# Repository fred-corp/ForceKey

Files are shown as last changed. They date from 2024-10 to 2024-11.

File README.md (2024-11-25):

# Force Key

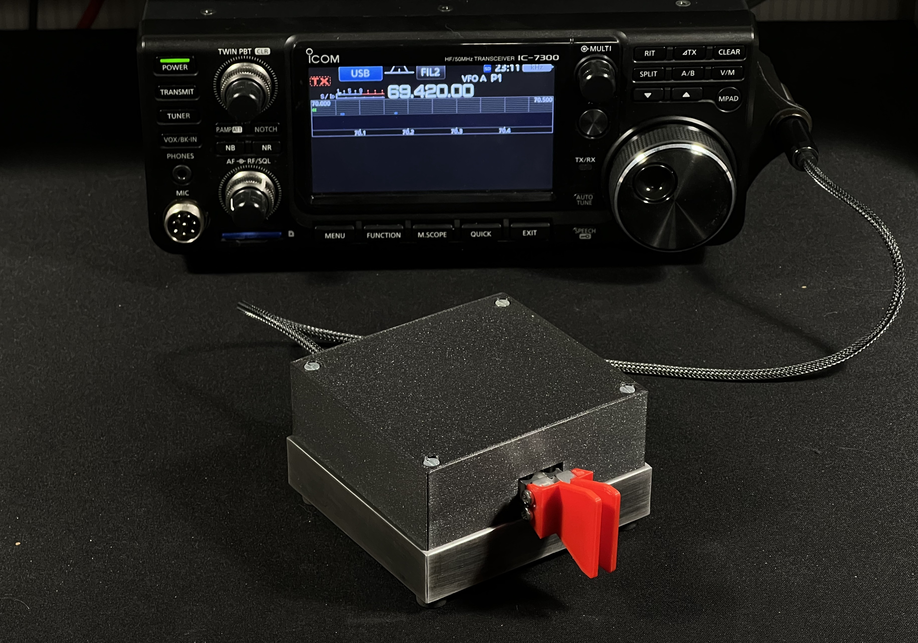
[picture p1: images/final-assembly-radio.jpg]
Force key image


## Description

The Force Key solid-state morse paddle key, which, as the name implies, uses force senors (load cells) to detect the user's input. It is designed to work in single-lever mode or twin-lever mode.  
The output is a standard 3.5mm stereo jack, which can be connected to any morse keyer or transceiver.

## Features

- Single-lever or twin-lever mode, or both at the same time
- Adjustable sensitivity in code
- TRS 3.5mm stereo jack output (tip = dot, ring = dash, sleeve = ground)
- Li-Ion battery powered
- USB-C port for charging
- Uses cheap Puya microcontroller

## Hardware

- PCB & other components in BOM
- 2x [100g load cells + HX711 amplifier](https://fr.aliexpress.com/item/1005001537354199.html) (make sure to get the 100g version !)
- TODO: add more details

The HX711 has to be modded to output data at 80Hz rate, which is done by lifting pin 15 and bridging it to pin 16 :  
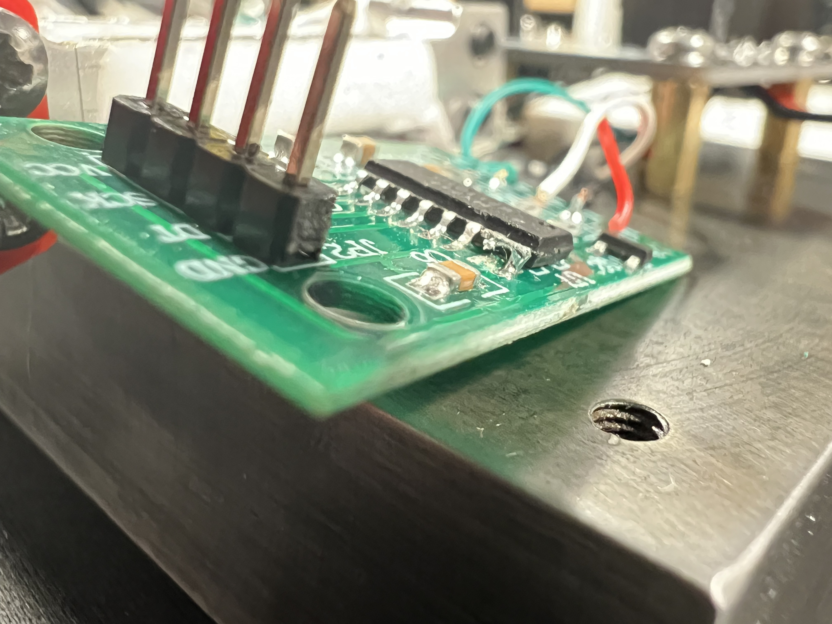
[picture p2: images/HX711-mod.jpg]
HX711 mod


## Inspiration

The Force key is inspired by the [Solid State Paddle by 9A5N](https://www.9a5n.eu/paddle.html), which is a beautiful product; but because of my student budget, I decided to make my own version.  
It was a nice challenge as I wanted to use the Puya PY32F002A microcontroller, which is not very common in the maker community.  
I also wanted to machine the base and load cell supports myself, which was exciting as I don't get to use the mills and lathes of my university very often as I'm an EE student.

Please consider buying the original product if you can afford it, it's a great product and it's worth the price (thanks [F4IEY](https://github.com/f4iey) for showing it to me in the first place !).

## Pictures

### 3D Render from Autodesk Fusion

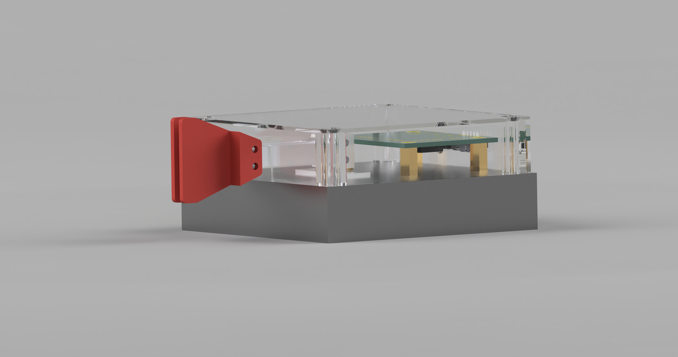
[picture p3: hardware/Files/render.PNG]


### Base machining

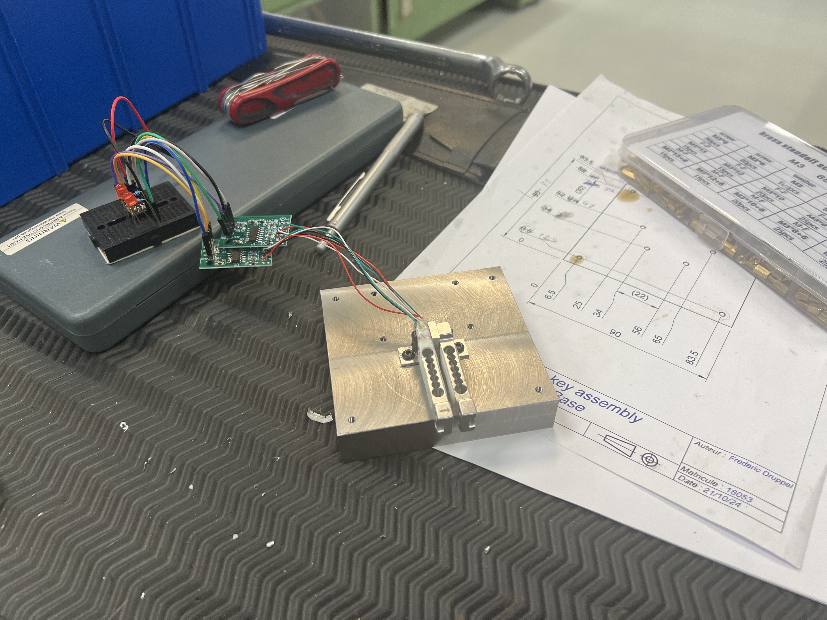
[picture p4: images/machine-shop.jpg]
machine shop


The final base ended up being 90x85x20mm due to the available scrap blank; the CAD was then adapted to fit the new dimensions.

It was amazing to be able to use the machines of my university. It took a whole afternoon to machine both parts (base and load-cell support), but it was really fun ! Thanks again to my teacher for all the help and advice.

### Base bluing

Before :  
before bluing

After :  
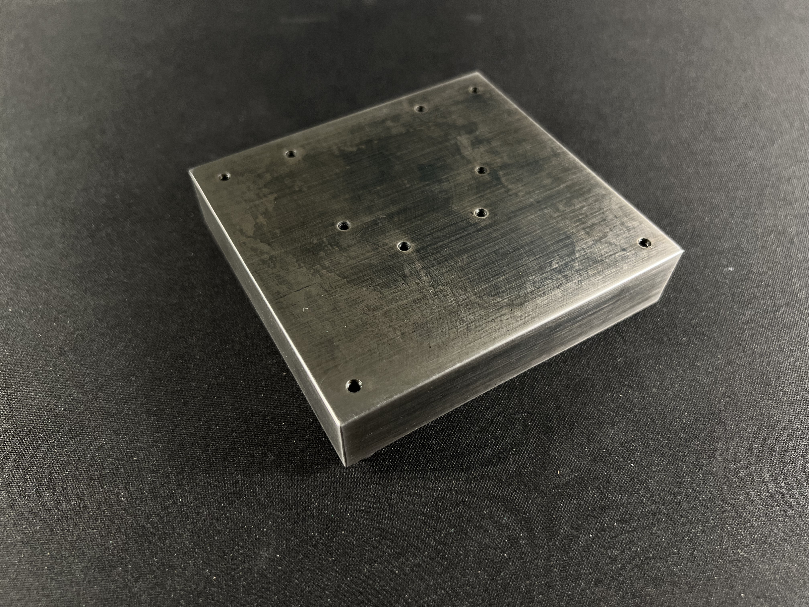
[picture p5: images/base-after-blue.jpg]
after bluing


After a lot of sanding with 180 and 320 scotch-brite, I used a cold bluing solution to give the base a nice black finish. It's not perfect nor uniform, but it gives a great old-school look to the base.

### Assembly

Partial assembly before bluing :  
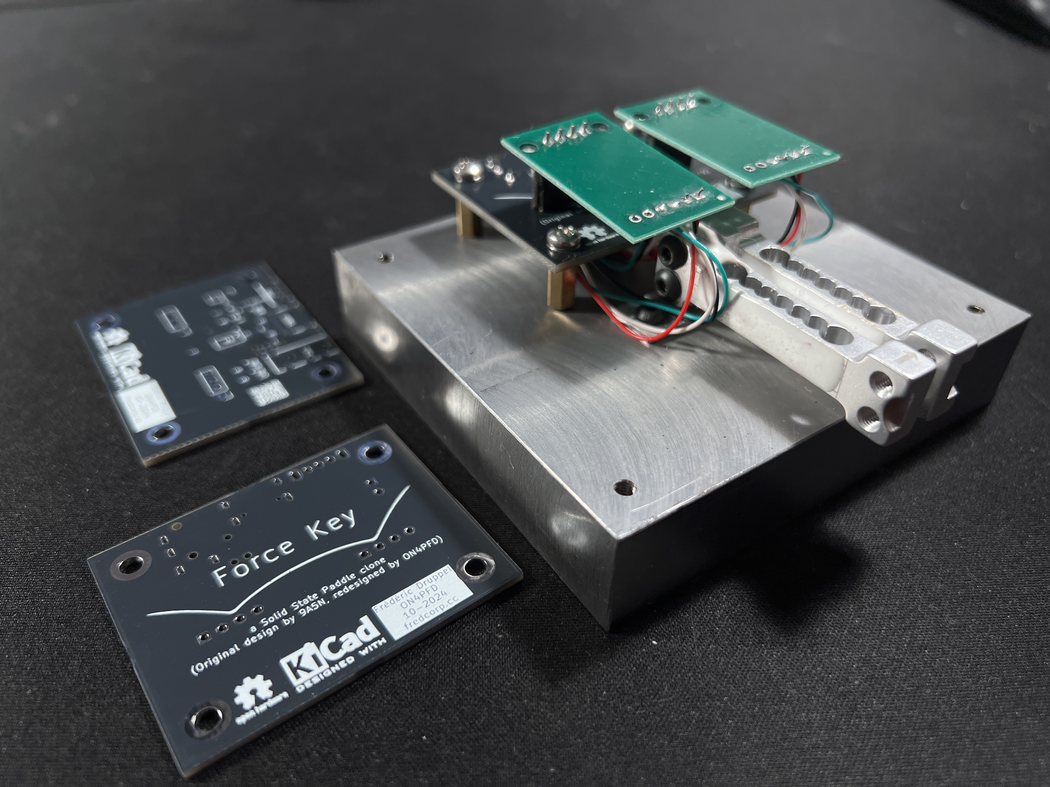
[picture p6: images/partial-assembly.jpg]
assembly


Assembly before bluing :  
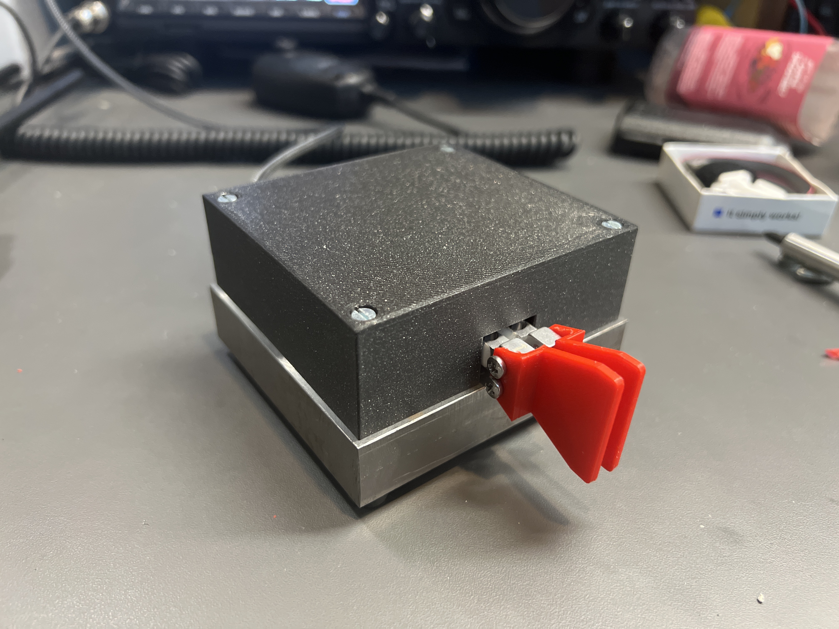
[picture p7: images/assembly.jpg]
assembly


Partial assembly after bluing :
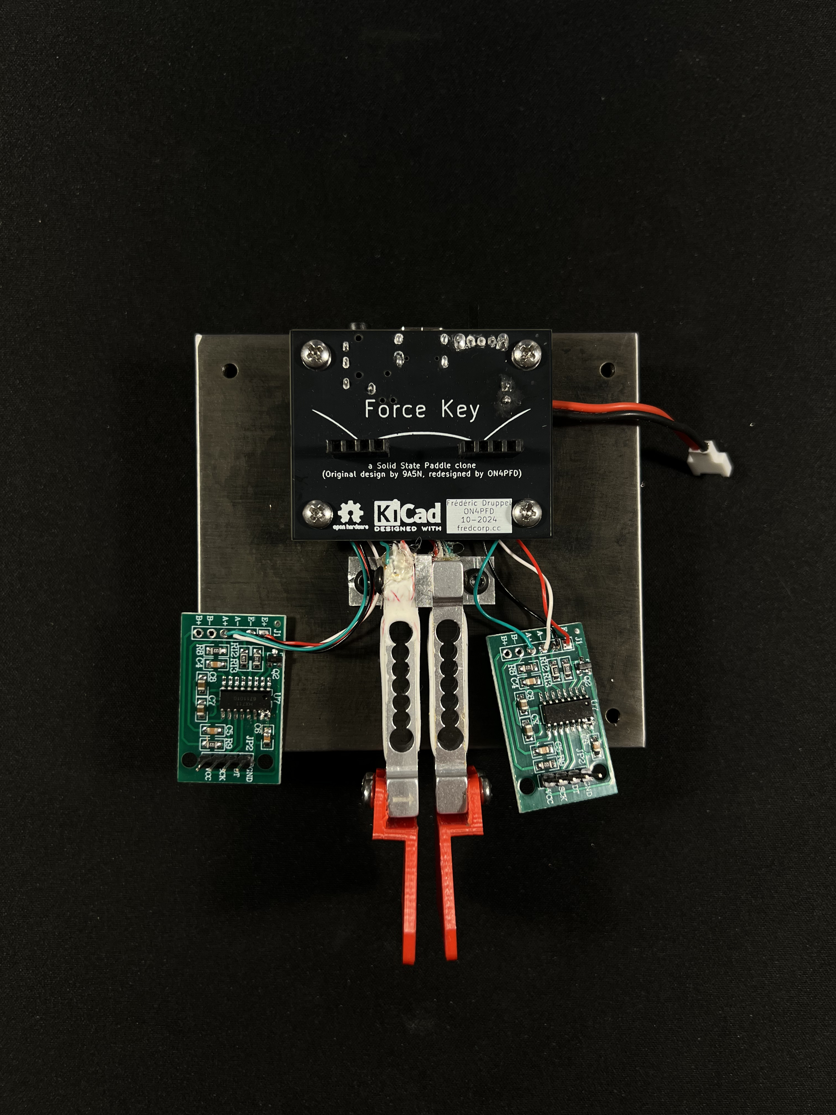
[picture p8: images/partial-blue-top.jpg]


Final assembly :

assembly

## License & Acknowledgements

Made with ❤️, lots of ☕️, and lack of 🛌  
Published under CreativeCommons BY-SA 4.0

  
This work is licensed under a [Creative Commons Attribution-ShareAlike 4.0 International License](http://creativecommons.org/licenses/by-sa/4.0/).

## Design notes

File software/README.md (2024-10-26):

# py32f0-template

* Template project for Puya PY32F0 MCU
* Supports GNU Arm Embedded Toolchain
* Supports J-Link and DAPLink/PyOCD programmers
* Supports IDE: VSCode

## Puya PY32F0 Family

PY32F0 are cost-effective Arm Cortex-M0+ microcontrollers featured with wide range operating voltage from 1.7V to 5.5V. Datesheets and Reference Manuals can be found at [WIKI](https://github.com/IOsetting/py32f0-template/wiki).

### PY32F002B

Frequency up to 24 MHz, 24 Kbytes of Flash memory, 3 Kbytes of SRAM.

* PY32F002B
  * PY32F002Bx(24KB Flash/3KB RAM)

### PY32F0xx

Frequency up to 48 MHz, 16 to 64 Kbytes of Flash memory, 3 to 8 Kbytes of SRAM.

* PY32F002A
  * PY32F002Ax5(20KB Flash/3KB RAM)
* PY32F003
  * PY32F003x4(16KB Flash/2KB RAM), PY32F003x6(32KB Flash/4KB RAM), PY32F003x8(64KB Flash/8KB RAM)
* PY32F030
  * PY32F030x4(16KB Flash/2KB RAM), PY32F030x6(32KB Flash/4KB RAM), PY32F030x8(64KB Flash/8KB RAM)

### PY32F07x

Frequency up to 72 MHz, 128 Kbytes of Flash memory, 16 Kbytes of SRAM, with more peripherals(CAN, USB)

* PY32F040
  * PY32F040xB(128KB Flash/16KB RAM)
* PY32F071
  * PY32F071xB(128KB Flash/16KB RAM)
* PY32F072
  * PY32F072xB(128KB Flash/16KB RAM)

## File Structure

```txt
├── Build                       # Build results
├── Docs                        # Datesheets and User Manuals
├── Examples
│   ├── PY32F002B               # PY32F002B examples
│   │   ├── HAL                 # HAL library examples
│   │   └── LL                  # LL(Low Layer) library examples
│   ├── PY32F07x                # PY32F07x examples
│   │   └── HAL                 # HAL library examples
│   └── PY32F0xx                # PY32F002A,PY32F003,PY32F030 examples
│       ├── FreeRTOS            # FreeRTOS examples
│       ├── HAL                 # HAL library examples
│       └── LL                  # LL(Low Layer) library examples
├── Libraries
│   ├── CMSIS
│   ├── EPaper                  # Waveshare e-paper library
│   ├── FreeRTOS                # FreeRTOS library
│   ├── LDScripts               # LD files
│   ├── PY32F002B_HAL_BSP       # PY32F002B HAL BSP
│   ├── PY32F002B_HAL_Driver    # PY32F002B HAL library
│   ├── PY32F002B_LL_BSP        # PY32F002B LL(low layer) BSP
│   ├── PY32F002B_LL_Driver     # PY32F002B LL library
│   ├── PY32F07x_HAL_BSP        # PY32F040/071/072 HAL BSP
│   ├── PY32F07x_HAL_Driver     # PY32F040/071/072 HAL library
│   ├── PY32F0xx_HAL_BSP        # PY32F002A/003/030 HAL BSP
│   ├── PY32F0xx_HAL_Driver     # PY32F002A/003/030 HAL library
│   ├── PY32F0xx_LL_BSP         # PY32F002A/003/030 LL BSP
│   └── PY32F0xx_LL_Driver      # PY32F002A/003/030 LL library
|
├── Makefile                    # Make config
├── Misc
│   ├── Flash
│   │   ├── JLinkDevices        # JLink flash loaders
│   │   └── Sources             # Flash algorithm source code
│   ├── Puya.PY32F0xx_DFP.x.pack # DFP pack file for PyOCD
│   └── SVD                     # SVD files
├── README.md
├── rules.mk                    # Pre-defined rules include in Makefile 
└── User                        # User application code
```

## Requirements

* PY32F0 EVB or boards of PY32F002/003/030 series
* Programmer
  * J-Link: J-Link OB programmer
  * PyOCD: DAPLink or J-Link
* SEGGER J-Link Software and Documentation pack [https://www.segger.com/downloads/jlink/](https://www.segger.com/downloads/jlink/)
* PyOCD [https://pyocd.io/](https://pyocd.io/)
* GNU Arm Embedded Toolchain

## Building

### 1. Install GNU Arm Embedded Toolchain

Download the toolchain from [Arm GNU Toolchain Downloads](https://developer.arm.com/downloads/-/arm-gnu-toolchain-downloads) according to your pc architecture, extract the files

```bash
sudo mkdir -p /opt/gcc-arm/
sudo tar xvf arm-gnu-toolchain-12.2.rel1-x86_64-arm-none-eabi.tar.xz -C /opt/gcc-arm/
cd /opt/gcc-arm/
sudo chown -R root:root arm-gnu-toolchain-12.2.rel1-x86_64-arm-none-eabi/
```

### 2. Clone This Repository

Clone this repository to local workspace

```bash
git clone https://github.com/IOsetting/py32f0-template.git
```

### 3. Install SEGGER J-Link Or PyOCD

#### Option 1: Install SEGGER J-Link

Download and install JLink from [J-Link / J-Trace Downloads](https://www.segger.com/downloads/jlink/).

The default installation directory is */opt/SEGGER*

Copy [Project directory]/Misc/Flash/JLinkDevices to [User home]/.config/SEGGER/

```bash
cp -r Misc/Flash/JLinkDevices/ "$HOME/Library/Application Support/SEGGER/JLinkDevices"
```

Read more: [https://wiki.segger.com/J-Link_Device_Support_Kit](https://wiki.segger.com/J-Link_Device_Support_Kit)

#### Option 2: Install PyOCD

Don't install from apt repository, because the version 0.13.1+dfsg-1 is too low for J-Link probe.

Install PyOCD from pip

```bash
pip uninstall pyocd
```

This will install PyOCD into:

```bash
/home/[user]/.local/bin/pyocd
/home/[user]/.local/bin/pyocd-gdbserver
/home/[user]/.local/lib/python3.10/site-packages/pyocd-0.34.2.dist-info/*
/home/[user]/.local/lib/python3.10/site-packages/pyocd/*
```

In Ubuntu, .profile will take care of the PATH, run `source ~/.profile` to make pyocd command available

### 4. Edit Makefile

Change the settings in Makefile

* **MCU_TYPE** The MCU type you are using
* **USE_LL_LIB** Puya provides two sets of library, HAL and LL, set `USE_LL_LIB ?= y` to use LL instead of HAL.
  * No LL Library for PY32F07x
* **ENABLE_PRINTF_FLOAT** set it to `y` to `-u _printf_float` to link options. This will increase the binary size.
* **USE_FREERTOS** Set `USE_FREERTOS ?= y` will include FreeRTOS in compilation
* **USE_DSP** Include CMSIS DSP or not
* **FLASH_PROGRM**
  * If you use J-Link, `FLASH_PROGRM` can be jlink or pyocd
  * If you use DAPLink, set `FLASH_PROGRM ?= pyocd`
  * ST-LINK is not supported yet.
* **ARM_TOOCHAIN** Make sure it points to the correct path of arm-none-eabi-gcc

```makefile
##### Project #####

PROJECT   ?= app
# The path for generated files
BUILD_DIR  = Build

# MCU types: 
#   PY32F002Ax5
#   PY32F002Bx5
#   PY32F003x6, PY32F003x8, 
#   PY32F030x6, PY32F030x8, 
#   PY32F072xB
MCU_TYPE  = PY32F072xB

##### Options #####

# Use LL library instead of HAL, y:yes, n:no
USE_LL_LIB        ?= n
# Enable printf float %f support, y:yes, n:no
ENABLE_PRINTF_FLOAT ?= n
# Build with FreeRTOS, y:yes, n:no
USE_FREERTOS      ?= n
# Build with CMSIS DSP functions, y:yes, n:no
USE_DSP           ?= n
# Programmer, jlink or pyocd
FLASH_PROGRM      ?= pyocd

##### Toolchains #######
ARM_TOOCHAIN      ?= /opt/gcc-arm/arm-gnu-toolchain-12.2.rel1-x86_64-arm-none-eabi/bin

# path to JLinkExe
JLINKEXE  ?= /opt/SEGGER/JLink/JLinkExe
# path to PyOCD
PYOCD_EXE  ?= pyocd
```

### 5. Compiling And Flashing

```bash
# clean source code
make clean
# build
make
# or make with verbose output
V=1 make
# flash
make flash
```

## Debugging In VSCode

Install Cortex Debug extension, add a new configuration in launch.json, e.g.

```json
{
    "armToolchainPath": "/opt/gcc-arm/arm-gnu-toolchain-12.2.rel1-x86_64-arm-none-eabi/bin/",
    "toolchainPrefix": "arm-none-eabi",
    "name": "Cortex Debug",
    "cwd": "${workspaceFolder}",
    "executable": "${workspaceFolder}/Build/app.elf",
    "request": "launch",        // can be launch or attach
    "type": "cortex-debug",
    "runToEntryPoint": "Reset_Handler", // "main" or other function name. runToMain is deprecated
    "servertype": "jlink",  // jlink, openocd, pyocd, pe and stutil
    "device": "PY32F030X8",
    "interface": "swd",
    "preLaunchTask": "build",  // Set this to run a task from tasks.json before starting a debug session
    // "preLaunchCommands": ["Build all"], // Uncomment this if not using preLaunchTask
    "svdFile": "${workspaceFolder}/Misc/SVD/py32f030xx.svd",  // svd for this part number
    "showDevDebugOutput": "vscode", // parsed, raw, vscode:vscode log and raw
    "swoConfig":
    {
        "enabled": true,
        "cpuFrequency": 8000000, // Target CPU frequency in Hz
        "swoFrequency":  4000000,
        "source": "probe", // either be “probe” to get directly from the debug probe, 
                           // or a serial port device to use a serial port external to the debug probe.
        "decoders":
        [
            {
                "label": "ITM port 0 output",
                "type": "console",
                "port": 0,
                "showOnStartup": true,
                "encoding": "ascii"
            }
        ]
    }
}
```

If Cortex Debug cannot find JLinkGDBServerCLExe, add the following line to settings.json

```json
"cortex-debug.JLinkGDBServerPath": "/opt/SEGGER/JLink/JLinkGDBServerCLExe",
```

## Try Other Examples

More examples can be found in *Examples* folder, copy and replace the files under *User* folder to try different examples.

## Links

* Puya Product Page(Datasheet download): <https://www.puyasemi.com/mcu_weichuliqi.html>

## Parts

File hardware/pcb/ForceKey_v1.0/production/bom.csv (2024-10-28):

Designator | Footprint | Quantity | Value | LCSC Part #
C1, C2, C3 | 0603 | 3 | 1u
C4, C5, C6 | 0603 | 3 | 10u
CN1 | AUDIO-TH_XKB_PJ-320A | 1 | PJ-320A | C2884926
J1 | PinHeader_1x02_P2.54mm_Vertical | 1 | PINHD_1x2_Male
J2, J3 | PinHeader_1x04_P2.54mm_Vertical | 2 | PINHD_1x4_Male
Q1, Q2, Q3 | SOT-323_SC-70_Handsoldering | 3 | BC817-40W
R1, R2, R5 | 0603 | 3 | 2k
R3, R4, R6, R7 | 0603 | 4 | 5.1k
SW1 | SW-TH_SK12D07VG6 | 1 | SK12D07VG6 | C7272161
U1 | SOP-8_L4.9-W3.9-P1.27-LS6.0-BL-1 | 1 | PY32F002AL15S6TU | C5292060
U2 | SOT-23-5 | 1 | ME6211C33M5
U3 | SOT-23-5_L2.9-W1.6-P0.95-LS2.8-BL | 1 | PJ4054B | C2911335
USB1 | USB-C-SMD_TYPE-C-6PIN-2MD-073 | 1 | TYPE-C 16PIN 2MD(073) | C2765186

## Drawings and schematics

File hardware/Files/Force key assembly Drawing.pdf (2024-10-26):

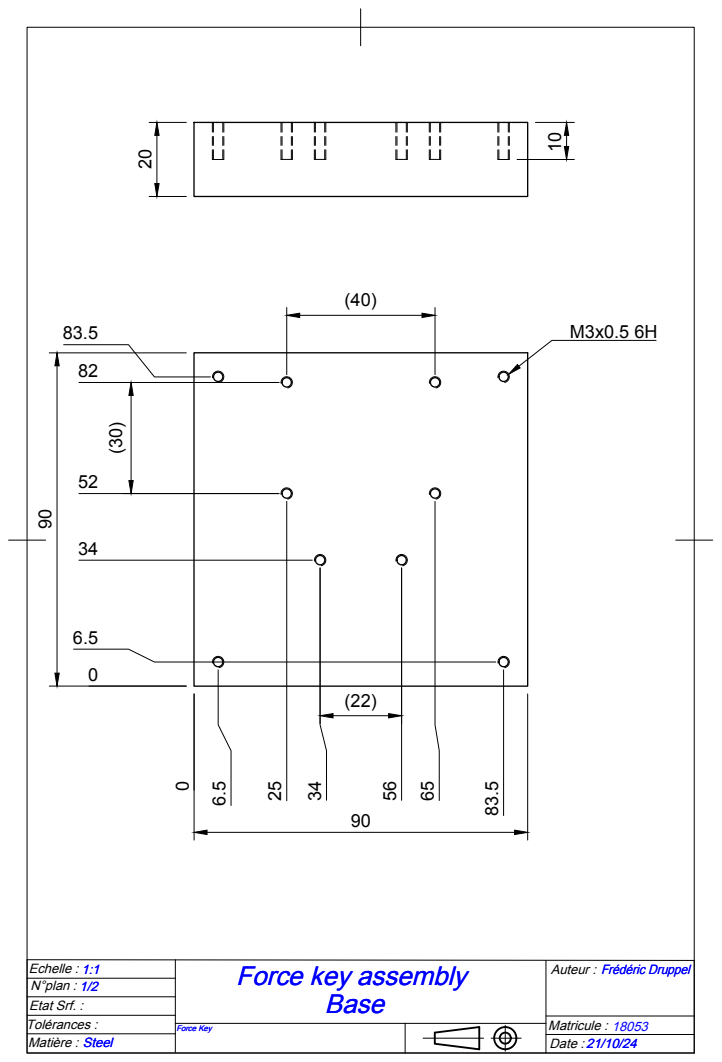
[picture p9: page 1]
N°plan :; Tolérances :; Etat Srf. :; Echelle :; Auteur :; Matricule :

Frédéric Druppel Force key assembly

Force Key

Matière : Steel Steel | Date : 21/10/24 21/10/24

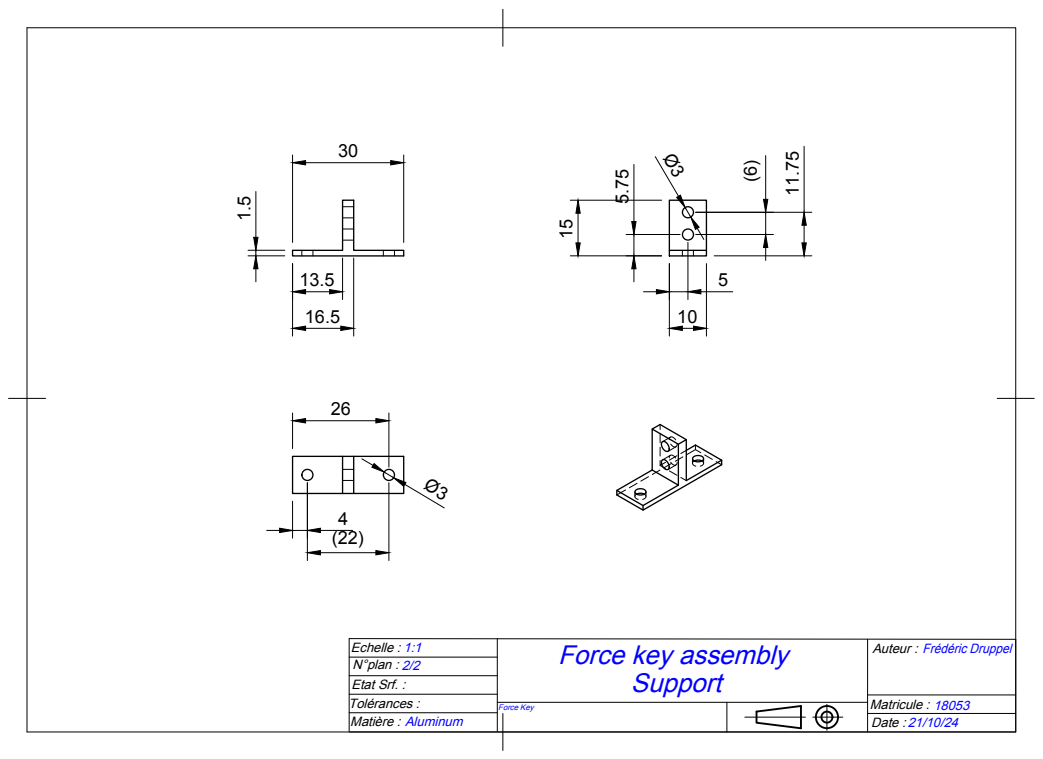
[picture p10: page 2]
N°plan :; Tolérances :; Etat Srf. :; Echelle :; Auteur :; Matricule :

Frédéric Druppel Force key assembly

Force Key

Matière : Aluminum | Date : 21/10/24

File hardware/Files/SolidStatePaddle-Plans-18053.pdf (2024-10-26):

# Pièces à usiner

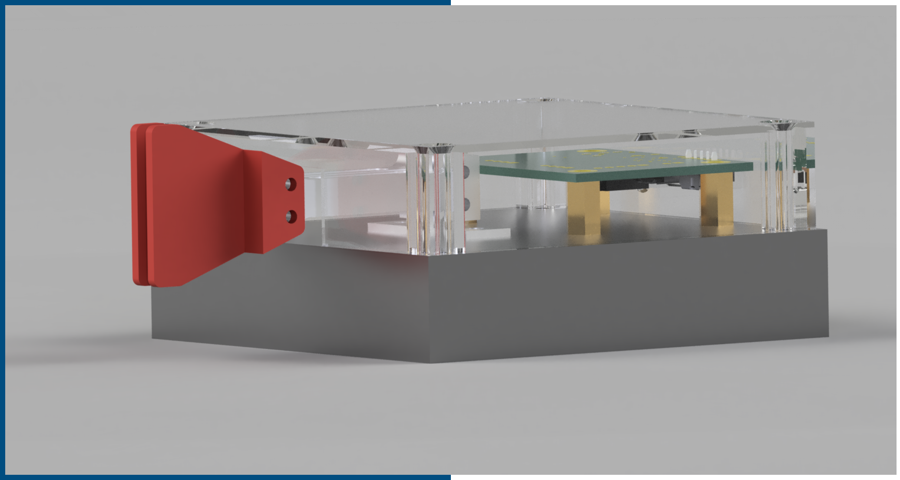
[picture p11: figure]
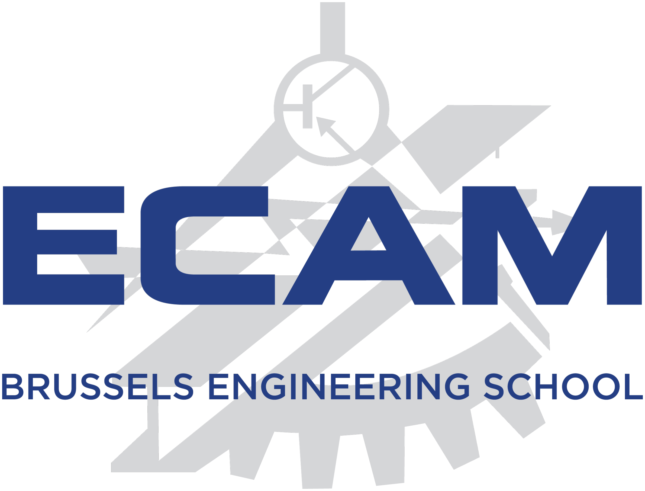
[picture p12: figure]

Frédéric Druppel | 18053
| 21-10-2024

# Solid-State Morse paddle

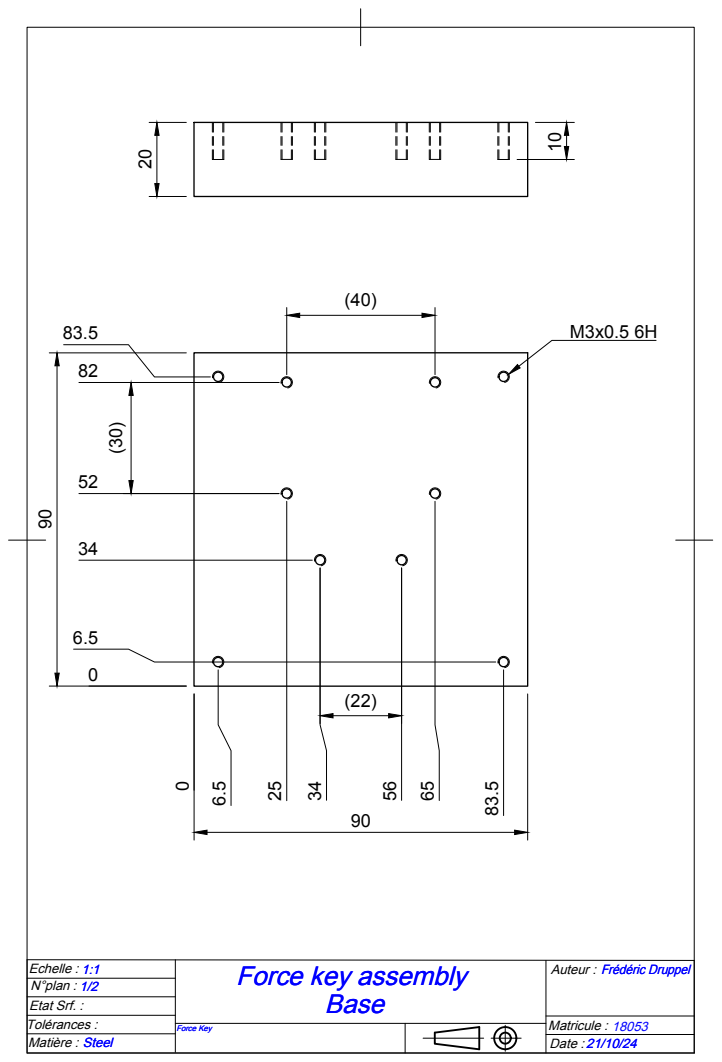
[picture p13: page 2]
N°plan :; Tolérances :; Etat Srf. :; Echelle :; Auteur :; Matricule :; Base

Frédéric Druppel Force key assembly

Force Key

Matière : Steel Steel | Date : 21/10/24 21/10/24

30

N°plan :; Tolérances :; Etat Srf. :; Echelle :; Auteur :; Matricule :

Frédéric Druppel Force key assembly
Support

Force Key

Matière : Aluminum | Date : 21/10/24

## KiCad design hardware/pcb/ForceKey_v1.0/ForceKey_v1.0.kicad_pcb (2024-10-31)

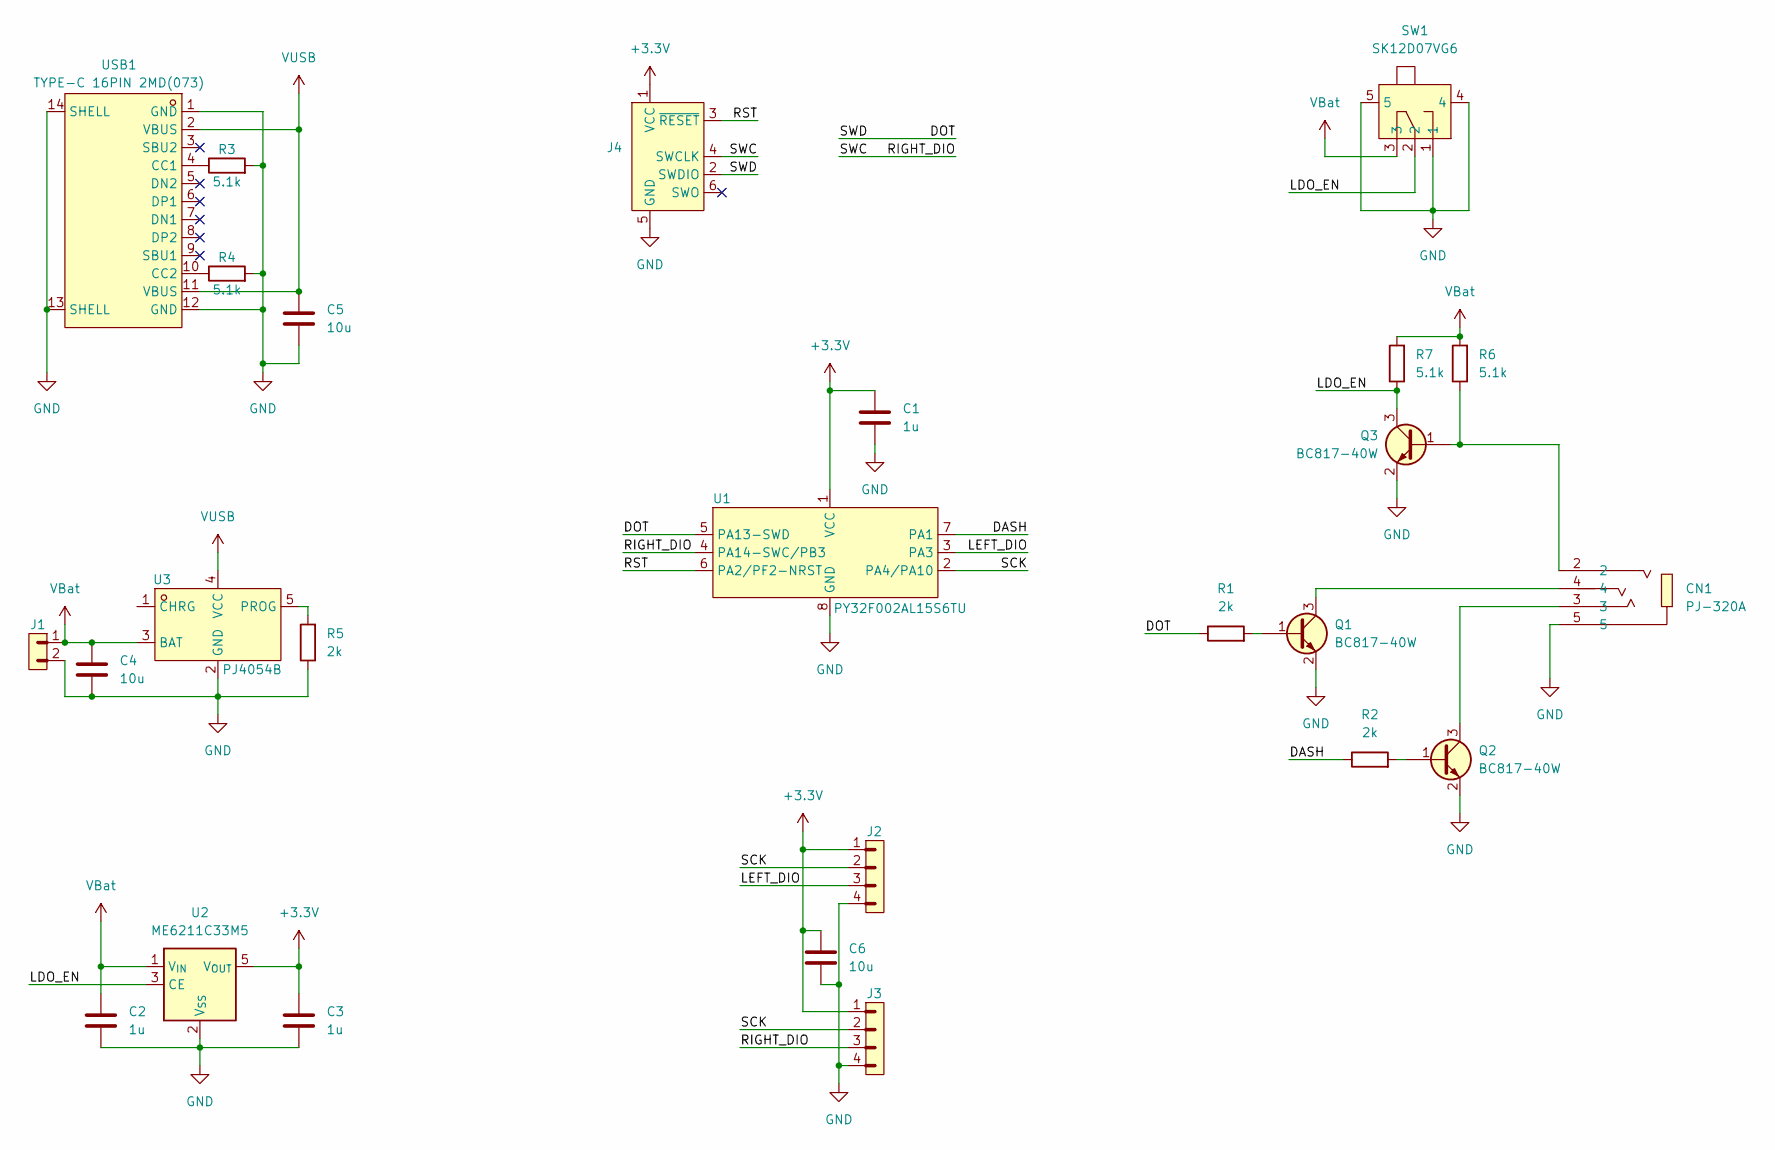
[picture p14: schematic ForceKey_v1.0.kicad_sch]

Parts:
C1, C2, C3: 1u; C_0603_1608Metric_Pad1.08x0.95mm_HandSolder
C4, C5, C6: 10u; C_0603_1608Metric_Pad1.08x0.95mm_HandSolder
CN1: PJ-320A; AUDIO-TH_XKB_PJ-320A; LCSC Part C2884926
J1: PINHD_1x2_Male; PinHeader_1x02_P2.54mm_Vertical
J2, J3: PINHD_1x4_Male; PinHeader_1x04_P2.54mm_Vertical
J4: Conn_ARM_SWD_TagConnect_TC2030-NL; Tag-Connect_TC2030-IDC-NL_2x03_P1.27mm_Vertical
Q1, Q2, Q3: BC817-40W; SOT-323_SC-70_Handsoldering
R1, R2, R5: 2k; R_0603_1608Metric_Pad0.98x0.95mm_HandSolder
R3, R4, R6, R7: 5.1k; R_0603_1608Metric_Pad0.98x0.95mm_HandSolder
SW1: SK12D07VG6; SW-TH_SK12D07VG6; LCSC Part C7272161
U1: PY32F002AL15S6TU; SOP-8_L4.9-W3.9-P1.27-LS6.0-BL-1; LCSC Part C5292060
U2: ME6211C33M5; SOT-23-5
U3: PJ4054B; SOT-23-5_L2.9-W1.6-P0.95-LS2.8-BL; LCSC Part C2911335
USB1: TYPE-C 16PIN 2MD(073); USB-C-SMD_TYPE-C-6PIN-2MD-073; LCSC Part C2765186

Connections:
+3.3V: C1.1, C3.1, C6.1, J2.1, J3.1, J4.1 (VCC), U1.1 (VCC), U2.5 (V_{OUT})
/DASH: R2.1, U1.7 (PA1)
/DOT: J4.2 (SWDIO), R1.1, U1.5 (PA13-SWD)
/LDO_EN: Q3.3 (C), R7.1, SW1.2, U2.3 (CE)
/LEFT_DIO: J2.3, U1.3 (PA3)
/RIGHT_DIO: J3.3, J4.4 (SWCLK), U1.4 (PA14-SWC/PB3)
/RST: J4.3 (~RESET), U1.6 (PA2/PF2-NRST)
/SCK: J2.2, J3.2, U1.2 (PA4/PA10)
GND: C1.2, C2.2, C3.2, C4.2, C5.2, C6.2, CN1.5, J1.2, J2.4, J3.4, J4.5 (GND), Q1.2 (E), Q2.2 (E), Q3.2 (E), R3.2, R4.2, R5.1, SW1.1, SW1.4, SW1.5, U1.8 (GND), U2.2 (V_{SS}), U3.2 (GND), USB1.1 (GND), USB1.12 (GND), USB1.13 (SHELL), USB1.14 (SHELL); also elsewhere on the board
unnamed: Q1.1 (B), R1.2
unnamed: CN1.4, Q1.3 (C)
unnamed: Q2.1 (B), R2.2
unnamed: CN1.3, Q2.3 (C)
unnamed: CN1.2, Q3.1 (B), R6.1
unnamed: R5.2, U3.5 (PROG)
unnamed: R3.1, USB1.4 (CC1)
unnamed: R4.1, USB1.10 (CC2)
VBat: C2.1, C4.1, J1.1, R6.2, R7.2, SW1.3, U2.1 (V_{IN}), U3.3 (BAT)
VUSB: C5.1, U3.4 (VCC), USB1.2 (VBUS), USB1.11 (VBUS)

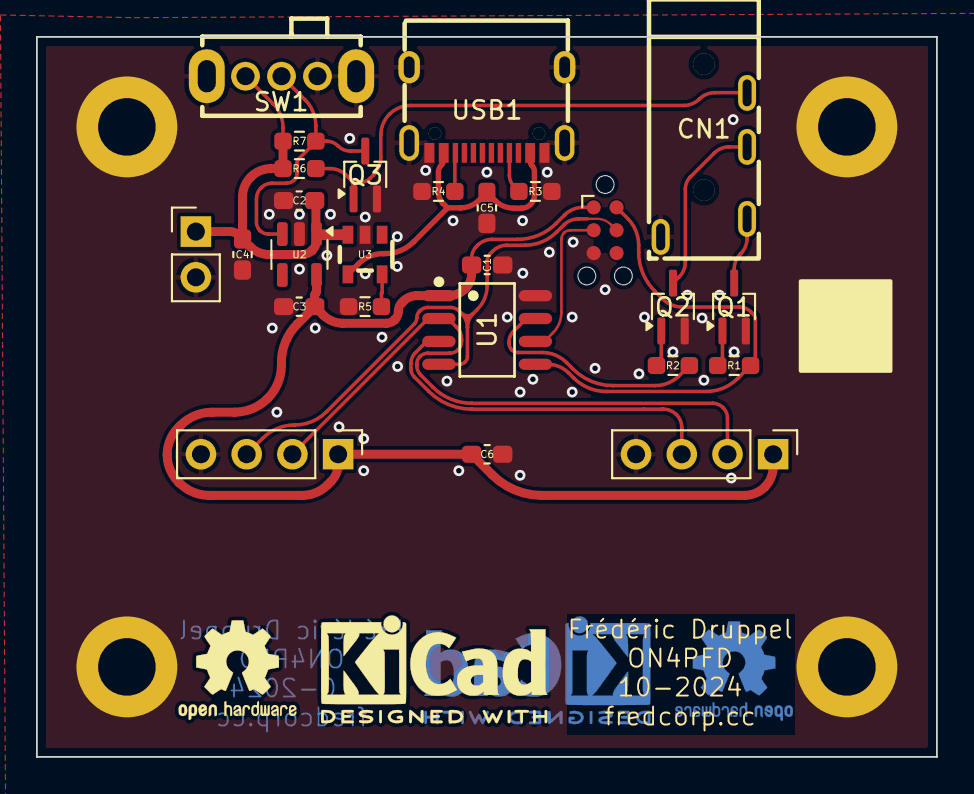
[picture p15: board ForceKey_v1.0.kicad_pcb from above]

Board: 2 copper layers, 50.0 x 40.0 mm, 30 parts (0 on the bottom side), 19 nets.

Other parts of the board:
H1, H2, H3, H4: MountingHole_3.2mm_M3_DIN965_Pad

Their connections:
GND: H1.1, H2.1, H3.1, H4.1; also elsewhere on the board

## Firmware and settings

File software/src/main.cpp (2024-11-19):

/**
 ******************************************************************************
 * @file    main.cpp
 * @author  Frédéric Druppel
 * @brief   Main program body
 ******************************************************************************
 *
 ******************************************************************************
 */

/* Includes ------------------------------------------------------------------*/
#include <PY32F002Ax5.h>
#include <py32f0xx_hal.h>
#include <py32f0xx_hal_gpio.h>
#include <stdbool.h>

/* Options -------------------------------------------------------------------*/
#define ONE_PADDLE  // Define this if for single paddle operation (compatible with two paddles)
#define TWO_PADDLES // Define this if for two paddles operation (need to have two paddles connected)

/* Pin definitions -----------------------------------------------------------*/
#define SCK_PIN GPIO_PIN_4
#define SCK_PORT GPIOA
#define LEFT_PIN GPIO_PIN_3
#define LEFT_PORT GPIOA
#define RIGHT_PIN GPIO_PIN_14
#define RIGHT_PORT GPIOA

#define DOT_PIN GPIO_PIN_13
#define DOT_PORT GPIOA
#define DASH_PIN GPIO_PIN_1
#define DASH_PORT GPIOA

/* Private define ------------------------------------------------------------*/
#define HIGH GPIO_PIN_SET
#define LOW GPIO_PIN_RESET

/* Parameters ----------------------------------------------------------------*/
const int32_t THRESHOLD_ON_LEFT   = 150000;
const int32_t THRESHOLD_OFF_LEFT  = 140000;
const int32_t THRESHOLD_ON_RIGHT  = 150000;
const int32_t THRESHOLD_OFF_RIGHT = 140000;

/* Private variables ---------------------------------------------------------*/
int32_t data_left_in   = 0;
int32_t cal_data_left  = 0;
bool cal_left          = false;
bool pressed_left      = false;
int32_t data_right_in  = 0;
int32_t cal_data_right = 0;
bool cal_right         = false;
bool pressed_right     = false;

/* Private user code ---------------------------------------------------------*/
/* Private macro -------------------------------------------------------------*/
/* Private function prototypes -----------------------------------------------*/
static void setup(void);
static void loop(void);
static bool paddles_ready(void);
static void read_paddles(bool *pressed_left, bool *pressed_right);

/* Compile checks -----------------------------------------------------------*/
// Raise compile error if one or both paddles are not connected
#if !defined(TWO_PADDLES) && !defined(ONE_PADDLE)
#error "Please define TWO_PADDLES or ONE_PADDLE"
#endif

/* Main function -------------------------------------------------------------*/

int main(void) {
    HAL_Init();

    HAL_Delay(100);

    setup();

    while (1) {
        loop();
    }
}

static void setup(void) {
    GPIO_InitTypeDef GPIO_InitStruct;

    __HAL_RCC_GPIOB_CLK_ENABLE();
    __HAL_RCC_GPIOA_CLK_ENABLE();

    GPIO_InitStruct.Pin   = SCK_PIN;
    GPIO_InitStruct.Mode  = GPIO_MODE_OUTPUT_PP;
    GPIO_InitStruct.Pull  = GPIO_PULLUP;
    GPIO_InitStruct.Speed = GPIO_SPEED_FREQ_HIGH;
    HAL_GPIO_Init(SCK_PORT, &GPIO_InitStruct);

    GPIO_InitStruct.Pin   = LEFT_PIN;
    GPIO_InitStruct.Mode  = GPIO_MODE_INPUT;
    GPIO_InitStruct.Pull  = GPIO_PULLUP;
    GPIO_InitStruct.Speed = GPIO_SPEED_FREQ_HIGH;
    HAL_GPIO_Init(LEFT_PORT, &GPIO_InitStruct);

#ifdef TWO_PADDLES
    GPIO_InitStruct.Pin   = RIGHT_PIN;
    GPIO_InitStruct.Mode  = GPIO_MODE_INPUT;
    GPIO_InitStruct.Pull  = GPIO_PULLUP;
    GPIO_InitStruct.Speed = GPIO_SPEED_FREQ_HIGH;
    HAL_GPIO_Init(RIGHT_PORT, &GPIO_InitStruct);
#endif

    GPIO_InitStruct.Pin   = DOT_PIN;
    GPIO_InitStruct.Mode  = GPIO_MODE_OUTPUT_PP;
    GPIO_InitStruct.Pull  = GPIO_NOPULL;
    GPIO_InitStruct.Speed = GPIO_SPEED_FREQ_HIGH;
    HAL_GPIO_Init(DOT_PORT, &GPIO_InitStruct);

    GPIO_InitStruct.Pin   = DASH_PIN;
    GPIO_InitStruct.Mode  = GPIO_MODE_OUTPUT_PP;
    GPIO_InitStruct.Pull  = GPIO_NOPULL;
    GPIO_InitStruct.Speed = GPIO_SPEED_FREQ_HIGH;
    HAL_GPIO_Init(DASH_PORT, &GPIO_InitStruct);

    HAL_GPIO_WritePin(SCK_PORT, SCK_PIN, LOW);
    HAL_GPIO_WritePin(DOT_PORT, DOT_PIN, LOW);
    HAL_GPIO_WritePin(DASH_PORT, DASH_PIN, LOW);

    // Set HX711 Gain and Channel a few times to stabilize the output
    for (int i = 0; i < 10; i++) {
        while (!paddles_ready()) {
        }
        if (paddles_ready()) {
            for (int i = 0; i < 27; i++) {
                HAL_GPIO_WritePin(SCK_PORT, SCK_PIN, HIGH);
                HAL_GPIO_WritePin(SCK_PORT, SCK_PIN, LOW);
            }
        }
    }
}

static void loop(void) {
    while (!paddles_ready()) {
    }
    if (paddles_ready()) {
        read_paddles(&pressed_left, &pressed_right);

        if (pressed_left) {
            HAL_GPIO_WritePin(DOT_PORT, DOT_PIN, HIGH);
        } else {
            HAL_GPIO_WritePin(DOT_PORT, DOT_PIN, LOW);
        }

        if (pressed_right) {
            HAL_GPIO_WritePin(DASH_PORT, DASH_PIN, HIGH);
        } else {
            HAL_GPIO_WritePin(DASH_PORT, DASH_PIN, LOW);
        }
    }
}

static bool paddles_ready(void) {
#ifdef TWO_PADDLES
    return (HAL_GPIO_ReadPin(LEFT_PORT, LEFT_PIN) == LOW && HAL_GPIO_ReadPin(RIGHT_PORT, RIGHT_PIN) == LOW);
#else
    return (HAL_GPIO_ReadPin(LEFT_PORT, LEFT_PIN) == LOW);
#endif
}

static void read_paddles(bool *_pressed_left, bool *_pressed_right) {
    uint32_t value_left  = 0;
    uint8_t data_left[3] = {0};
    uint8_t filler_left  = 0x00;
#ifdef TWO_PADDLES
    uint32_t value_right  = 0;
    uint8_t data_right[3] = {0};
    uint8_t filler_right  = 0x00;
#endif

    for (int i = 0; i < 25; i++) {
        HAL_GPIO_WritePin(SCK_PORT, SCK_PIN, HIGH);
        if (i < 8) {
            data_left[2] = (data_left[2] << 1) | (HAL_GPIO_ReadPin(LEFT_PORT, LEFT_PIN) == LOW ? 0 : 1);
#ifdef TWO_PADDLES
            data_right[2] = (data_right[2] << 1) | (HAL_GPIO_ReadPin(RIGHT_PORT, RIGHT_PIN) == LOW ? 0 : 1);
#endif
        } else if (i >= 8 && i < 16) {
            data_left[1] = (data_left[1] << 1) | (HAL_GPIO_ReadPin(LEFT_PORT, LEFT_PIN) == LOW ? 0 : 1);
#ifdef TWO_PADDLES
            data_right[1] = (data_right[1] << 1) | (HAL_GPIO_ReadPin(RIGHT_PORT, RIGHT_PIN) == LOW ? 0 : 1);
#endif
        } else if (i >= 16 && i < 24) {
            data_left[0] = (data_left[0] << 1) | (HAL_GPIO_ReadPin(LEFT_PORT, LEFT_PIN) == LOW ? 0 : 1);
#ifdef TWO_PADDLES
            data_right[0] = (data_right[0] << 1) | (HAL_GPIO_ReadPin(RIGHT_PORT, RIGHT_PIN) == LOW ? 0 : 1);
#endif
        }
        HAL_GPIO_WritePin(SCK_PORT, SCK_PIN, LOW);
    }

    if (data_left[2] & 0x80) {
        filler_left = 0xFF;
    } else {
        filler_left = 0x00;
    }
    value_left   = value_left << 8 | filler_left;
    value_left   = value_left << 8 | data_left[2];
    value_left   = value_left << 8 | data_left[1];
    value_left   = value_left << 8 | data_left[0];

    data_left_in = value_left;

    if (!cal_left) {
        cal_data_left = data_left_in;
        cal_left      = true;
    }

    if (data_left_in - cal_data_left >= THRESHOLD_ON_LEFT) {
        *_pressed_left = true;
    } else if (data_left_in - cal_data_left <= THRESHOLD_OFF_LEFT) {
        *_pressed_left = false;
    }

#ifdef TWO_PADDLES
    if (data_right[2] & 0x80) {
        filler_right = 0xFF;
    } else {
        filler_right = 0x00;
    }
    value_right   = value_right << 8 | filler_right;
    value_right   = value_right << 8 | data_right[2];
    value_right   = value_right << 8 | data_right[1];
    value_right   = value_right << 8 | data_right[0];

    data_right_in = value_right;

    if (!cal_right) {
        cal_data_right = data_right_in;
        cal_right      = true;
    }

    if (data_right_in - cal_data_right >= THRESHOLD_ON_RIGHT) {
        *_pressed_right = true;
#ifdef ONE_PADDLE
        return;
#endif
    } else if (data_right_in - cal_data_right <= THRESHOLD_OFF_RIGHT) {
        *_pressed_right = false;
    }
#endif

#ifdef ONE_PADDLE
    if (data_left_in - cal_data_left <= -THRESHOLD_ON_LEFT) {
        *_pressed_right = true;
    } else if (data_left_in - cal_data_left >= -THRESHOLD_OFF_LEFT) {
        *_pressed_right = false;
    }
#endif
}

void APP_ErrorHandler(void) {
    while (1)
        ;
}

#ifdef USE_FULL_ASSERT

void assert_failed(uint8_t *file, uint32_t line) {
    while (1) {
    }
}
#endif /* USE_FULL_ASSERT */

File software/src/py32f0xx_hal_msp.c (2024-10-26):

/**
 ******************************************************************************
 * @file    py32f0xx_hal_msp.c
 * @author  MCU Application Team
 * @brief   This file provides code for the MSP Initialization
 *          and de-Initialization codes.
 ******************************************************************************
 * @attention
 *
 * <h2><center>&copy; Copyright (c) Puya Semiconductor Co.
 * All rights reserved.</center></h2>
 *
 * <h2><center>&copy; Copyright (c) 2016 STMicroelectronics.
 * All rights reserved.</center></h2>
 *
 * This software component is licensed by ST under BSD 3-Clause license,
 * the "License"; You may not use this file except in compliance with the
 * License. You may obtain a copy of the License at:
 *                        opensource.org/licenses/BSD-3-Clause
 *
 ******************************************************************************
 */

/* Includes ------------------------------------------------------------------*/
#include "py32f0xx_hal.h"

/* Private typedef -----------------------------------------------------------*/
/* Private define ------------------------------------------------------------*/
/* Private macro -------------------------------------------------------------*/
/* Private variables ---------------------------------------------------------*/
/* Private function prototypes -----------------------------------------------*/
/* External functions --------------------------------------------------------*/

/**
 * @brief  Configure the Flash prefetch and the Instruction cache,
 *         the time base source, NVIC and any required global low level hardware
 *         by calling the HAL_MspInit() callback function from HAL_Init()
 *
 */
void HAL_MspInit(void) {
}

/************************ (C) COPYRIGHT Puya *****END OF FILE******************/

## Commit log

2024-10-12 add initial KiCad files for ForceKey v1.0 including symbol and footprint libraries
    [ForceKey_v1.0.kicad_pcb, ForceKey_v1.0.kicad_sch]
2024-10-14 added switch
2024-10-14 added switch & basic PCB layout draft
    [ForceKey_v1.0.kicad_pcb, ForceKey_v1.0.kicad_sch]
2024-10-14 added power traces, updated footprints
    [ForceKey_v1.0.kicad_pcb, ForceKey_v1.0.kicad_sch]
2024-10-26 updated PCB
    [ForceKey_v1.0.kicad_pcb]
2024-10-27 fixed missing bracket
2024-10-27 fixed includes for IntelliSense
    [main.cpp]
2024-10-27 added dot & dash pin handling
2024-10-28 fixed pin overlap with LED (dev), fixed variable names There was the CQWW contest, I didn't sleep much and coded between my shifts \^\^'
    [main.cpp]
2024-10-28 Finished Schematic and PCB
    [ForceKey_v1.0.kicad_pcb, ForceKey_v1.0.kicad_sch]
2024-10-28 created fab files
    [bom.csv, designators.csv, positions.csv]
2024-10-31 updated J-Link command to reset target before erase Fixed "bricked" behavior of the PY32F002A chip even if nRST pin is not used as GPIO
2024-10-31 updated PCB settings
    [ForceKey_v1.0.kicad_pcb]
2024-11-09 updated code to match PCB
2024-11-25 updated README with new images and additional details on HX711 modification and assembly process
2026-06-22 added schematic PDF
